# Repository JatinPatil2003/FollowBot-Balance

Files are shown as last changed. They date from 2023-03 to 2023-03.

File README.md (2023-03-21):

# FollowBot-Balance
It is a Self balancing robot whhich has a feature of following human. It uses a control system to balance the bot and opencv and media pipe to detect human, it takes video stream from esp32cam and process that video and revert back coordinates of human to the server's ip address.

This Self balancing bot can balance at a point, can be contolled over remote and can hollow human

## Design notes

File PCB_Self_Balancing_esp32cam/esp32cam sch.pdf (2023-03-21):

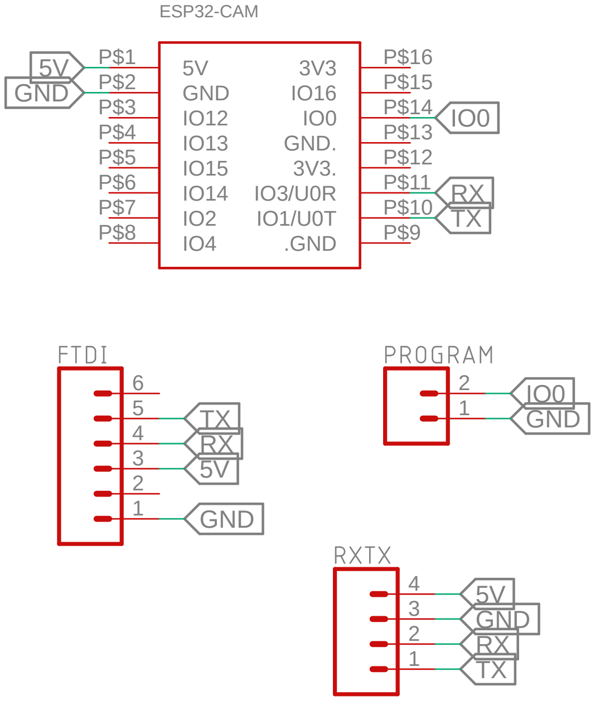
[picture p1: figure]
5V P$1 GND P$2 IO12 P$3 IO13 P$4 IO15 P$5 IO14 P$6 IO2 P$7; .GND; P$12 GND.; ESP32-CAM; GND

22-03-2023 03:23 AM f=2.50 C:\Users\jatin\OneDrive\Documents\EAGLE\projects\PCB_Self_Balancing_esp32cam\Self_Balancing esp32cam.sch (Sheet: 1/1)

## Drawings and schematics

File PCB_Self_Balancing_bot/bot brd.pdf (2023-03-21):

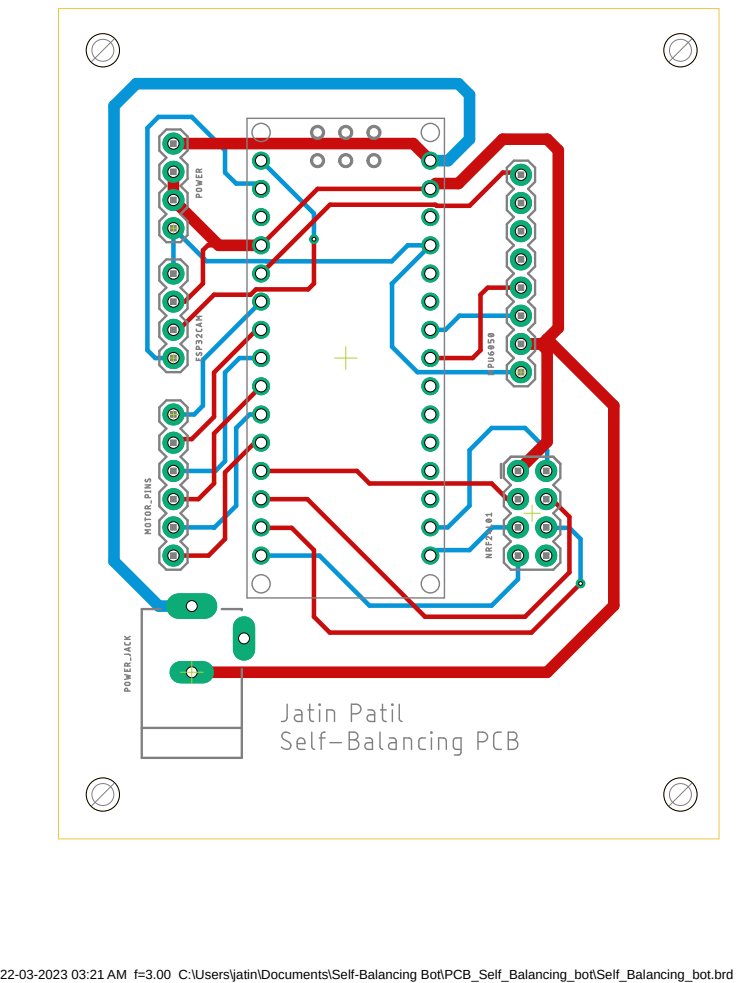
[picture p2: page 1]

22-03-2023 03:21 AM f=3.00 C:\Users\jatin\Documents\Self-Balancing Bot\PCB_Self_Balancing_bot\Self_Balancing_bot.brd

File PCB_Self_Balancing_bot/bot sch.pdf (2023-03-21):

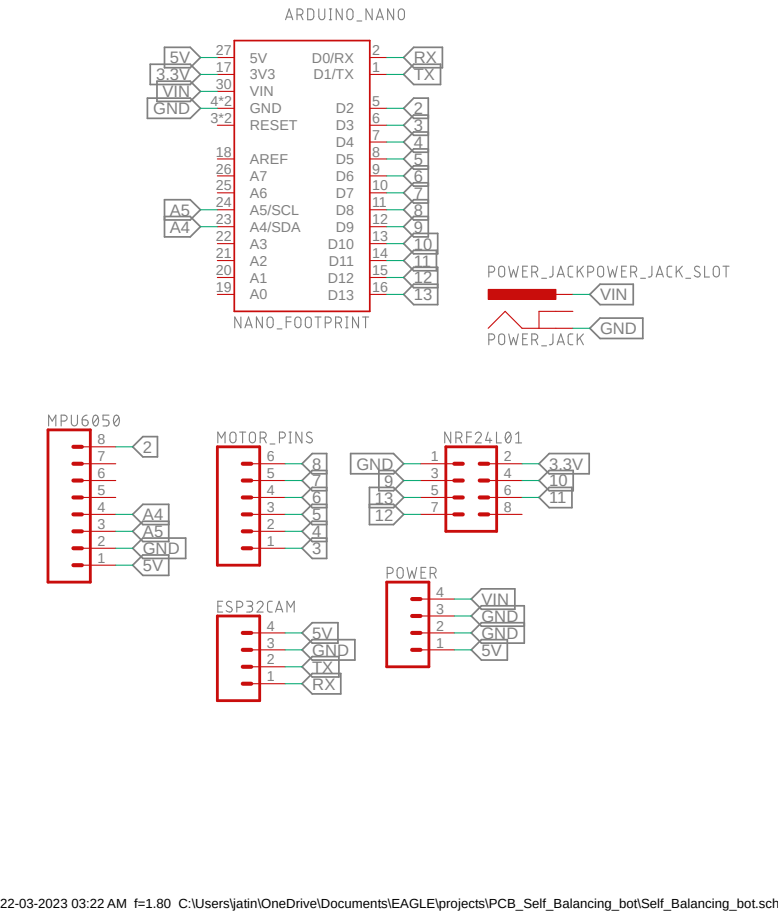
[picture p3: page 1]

22-03-2023 03:22 AM f=1.80 C:\Users\jatin\OneDrive\Documents\EAGLE\projects\PCB_Self_Balancing_bot\Self_Balancing_bot.sch (Sheet: 1/1)

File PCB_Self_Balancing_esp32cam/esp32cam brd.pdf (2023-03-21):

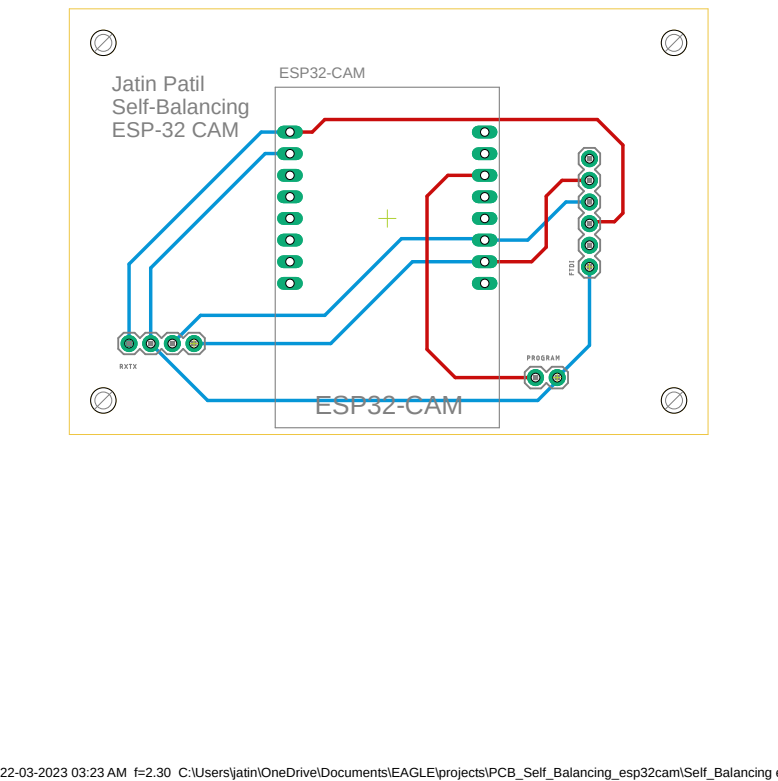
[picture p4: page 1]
ESP32-CAM; Jatin Patil Self-Balancing ESP-32 CAM

22-03-2023 03:23 AM f=2.30 C:\Users\jatin\OneDrive\Documents\EAGLE\projects\PCB_Self_Balancing_esp32cam\Self_Balancing esp32cam.brd

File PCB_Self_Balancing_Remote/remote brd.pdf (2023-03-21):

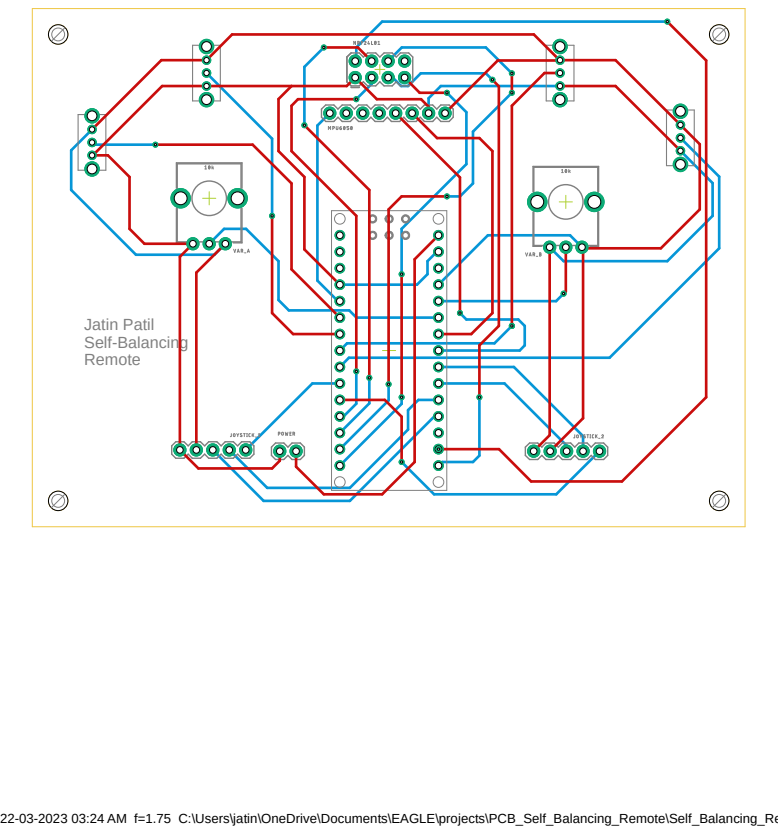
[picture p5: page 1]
Jatin Patil Self-Balancing Remote

22-03-2023 03:24 AM f=1.75 C:\Users\jatin\OneDrive\Documents\EAGLE\projects\PCB_Self_Balancing_Remote\Self_Balancing_Remote.brd

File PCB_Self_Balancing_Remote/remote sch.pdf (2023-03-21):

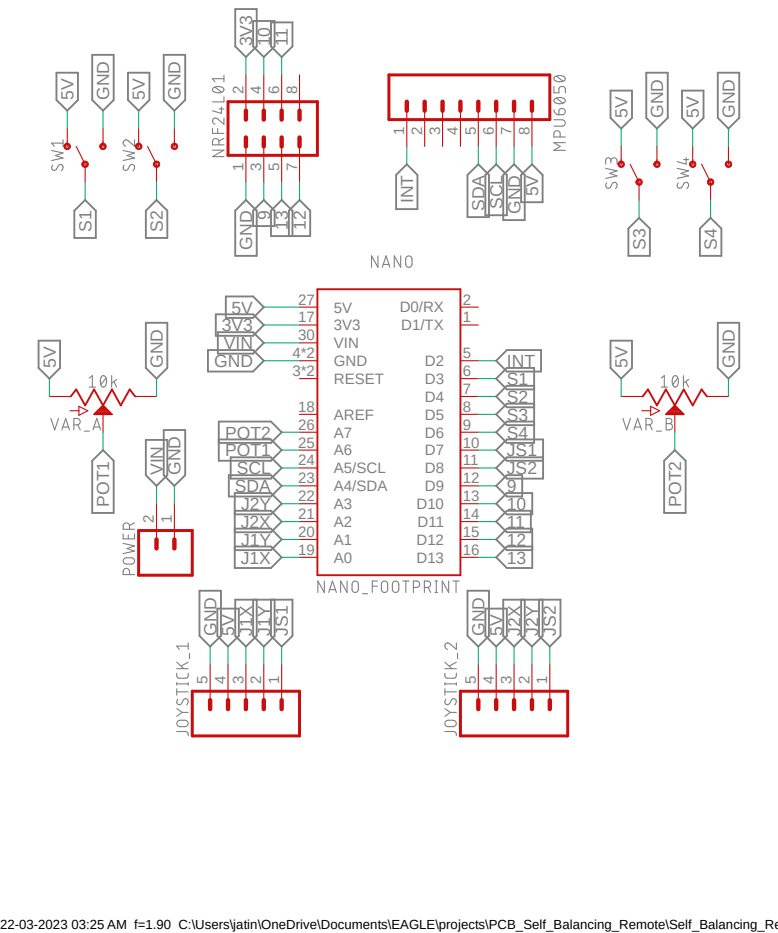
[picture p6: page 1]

22-03-2023 03:25 AM f=1.90 C:\Users\jatin\OneDrive\Documents\EAGLE\projects\PCB_Self_Balancing_Remote\Self_Balancing_Remote.sch (Sheet: 1/1)

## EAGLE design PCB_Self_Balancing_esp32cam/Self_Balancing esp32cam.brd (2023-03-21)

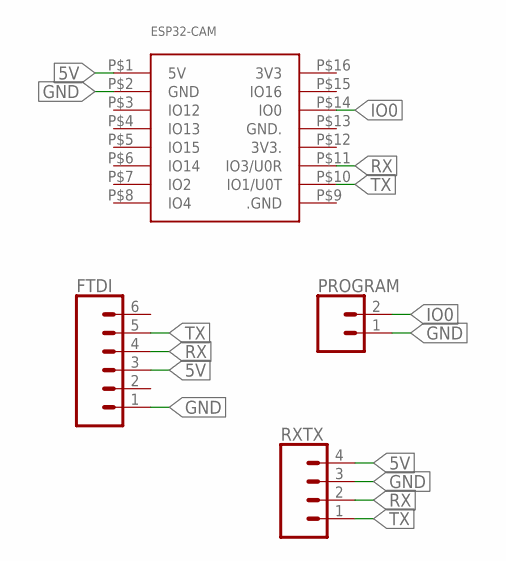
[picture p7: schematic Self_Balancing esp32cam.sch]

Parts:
ESP32-CAM: ESP32-CAM
FTDI: CONN_06SILK_FEMALE_PTH; 1X06
PROGRAM: CONN_02; 1X02
RXTX: CONN_04PTH; 1X04

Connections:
5V: ESP32-CAM.P$1 (5V), FTDI.3, RXTX.4
GND: ESP32-CAM.P$2 (GND), FTDI.1, PROGRAM.1, RXTX.3
IO0: ESP32-CAM.P$14 (IO0), PROGRAM.2
RX: ESP32-CAM.P$11 (IO3/U0R), FTDI.4, RXTX.2
TX: ESP32-CAM.P$10 (IO1/U0T), FTDI.5, RXTX.1

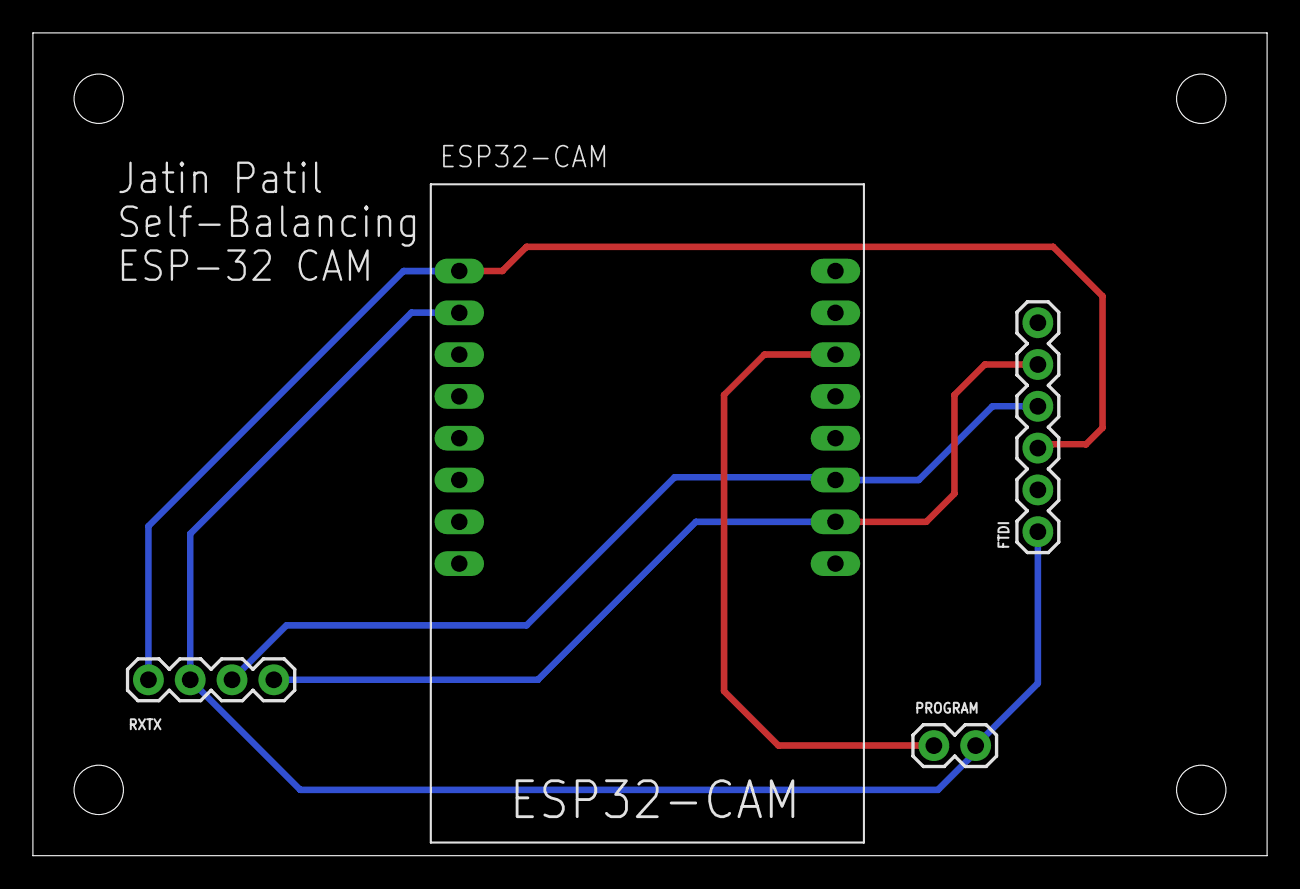
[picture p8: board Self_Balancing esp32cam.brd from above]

Board: 2 copper layers, 75.0 x 50.0 mm, 4 parts (0 on the bottom side), 5 nets.

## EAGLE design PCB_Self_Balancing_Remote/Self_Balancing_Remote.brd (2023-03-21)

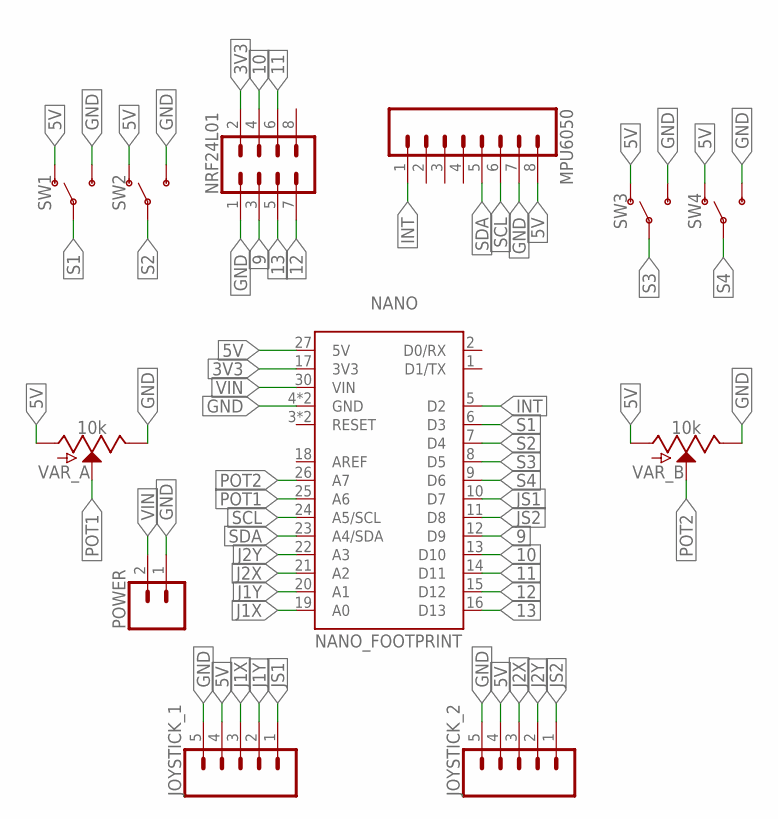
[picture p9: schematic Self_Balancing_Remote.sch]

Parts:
JOYSTICK_1, JOYSTICK_2: CONN_05; 1X05
MPU6050: CONN_08"; 1X08
NANO: NANO_FOOTPRINT; NANO
NRF24L01: CONN_04X2; 2X4
POWER: CONN_02; 1X02
SW1, SW2, SW3, SW4: SWITCH-SPDT-PTH-8.6X4.3MM; SWITCH_SPDT_8.6X4.3MM
VAR_A: 10k; POT-PTH-ALPS-KIT
VAR_B: 10k; POT-PTH-ALPS-KIT

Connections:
3V3: NANO.17 (3V3), NRF24L01.2
5V: JOYSTICK_1.4, JOYSTICK_2.4, MPU6050.8, NANO.27 (5V), SW1.1 (O), SW2.1 (O), SW3.1 (O), SW4.1 (O), VAR_A.P$3 (A), VAR_B.P$3 (A)
9: NANO.12 (D9), NRF24L01.3
10: NANO.13 (D10), NRF24L01.4
11: NANO.14 (D11), NRF24L01.6
12: NANO.15 (D12), NRF24L01.7
13: NANO.16 (D13), NRF24L01.5
GND: JOYSTICK_1.5, JOYSTICK_2.5, MPU6050.7, NANO.4 (GND), NANO.29 (GND), NRF24L01.1, POWER.1, SW1.3 (S), SW2.3 (S), SW3.3 (S), SW4.3 (S), VAR_A.P$1 (E), VAR_B.P$1 (E)
INT: MPU6050.1, NANO.5 (D2)
J1X: JOYSTICK_1.3, NANO.19 (A0)
J1Y: JOYSTICK_1.2, NANO.20 (A1)
J2X: JOYSTICK_2.3, NANO.21 (A2)
J2Y: JOYSTICK_2.2, NANO.22 (A3)
JS1: JOYSTICK_1.1, NANO.10 (D7)
JS2: JOYSTICK_2.1, NANO.11 (D8)
POT1: NANO.25 (A6), VAR_A.P$2 (S)
POT2: NANO.26 (A7), VAR_B.P$2 (S)
S1: NANO.6 (D3), SW1.2
S2: NANO.7 (D4), SW2.2
S3: NANO.8 (D5), SW3.2
S4: NANO.9 (D6), SW4.2
SCL: MPU6050.6, NANO.24 (A5/SCL)
SDA: MPU6050.5, NANO.23 (A4/SDA)
VIN: NANO.30 (VIN), POWER.2

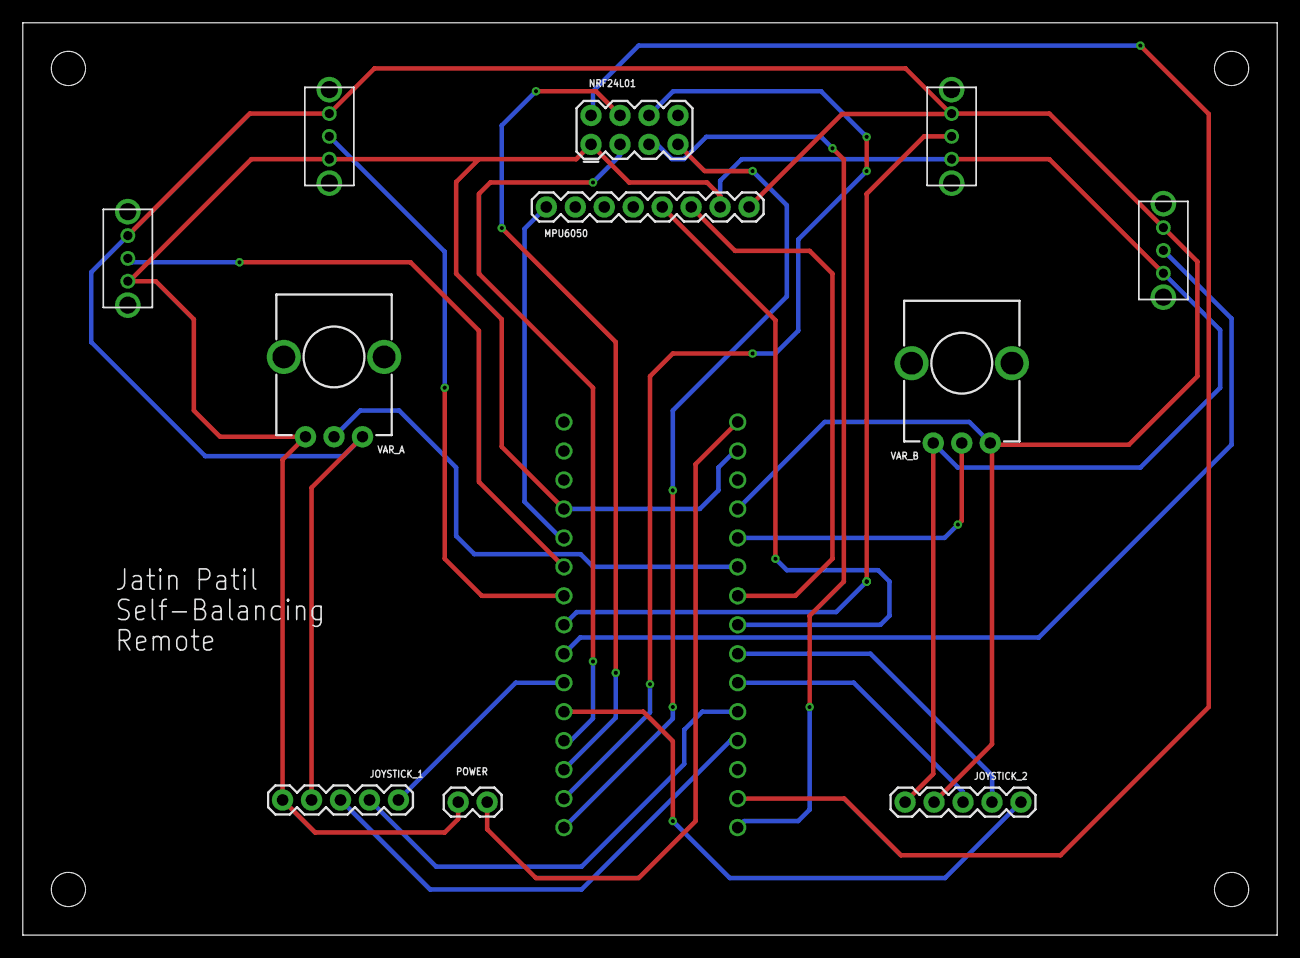
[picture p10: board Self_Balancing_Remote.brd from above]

Board: 2 copper layers, 110.0 x 80.0 mm, 12 parts (0 on the bottom side), 24 nets.

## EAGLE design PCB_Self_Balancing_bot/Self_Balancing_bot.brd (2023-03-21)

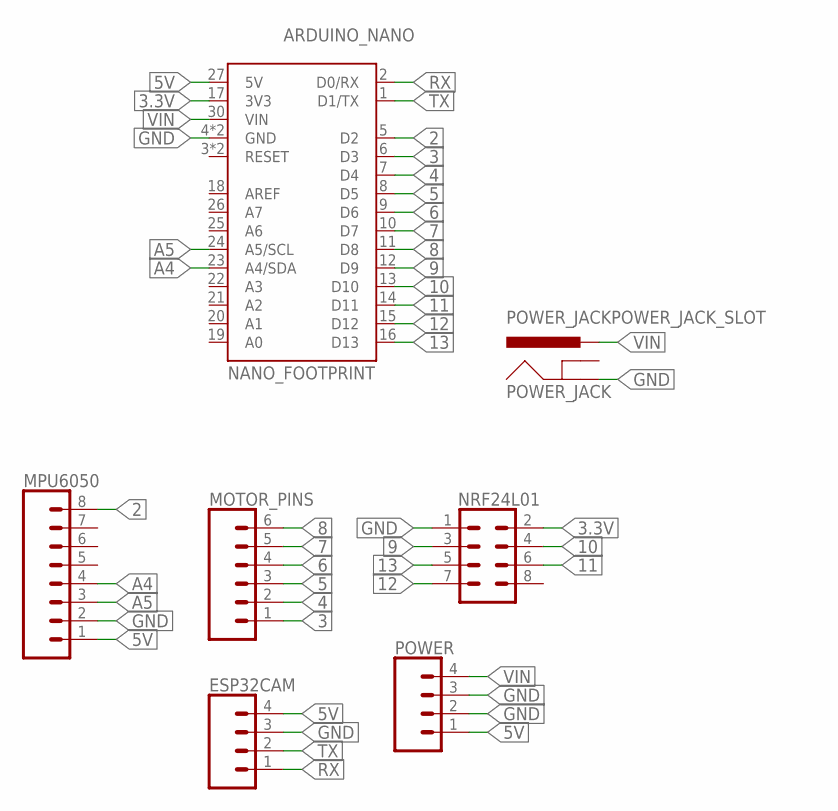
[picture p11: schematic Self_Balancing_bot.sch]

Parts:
ARDUINO_NANO: NANO_FOOTPRINT; NANO
ESP32CAM: CONN_04PTH; 1X04
MOTOR_PINS: CONN_06SILK_FEMALE_PTH; 1X06
MPU6050: CONN_08"; 1X08
NRF24L01: CONN_04X2; 2X4
POWER: CONN_04PTH; 1X04
POWER_JACK: POWER_JACKPOWER_JACK_SLOT; POWER_JACK_PTH_SLOT

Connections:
2: ARDUINO_NANO.5 (D2), MPU6050.8
3: ARDUINO_NANO.6 (D3), MOTOR_PINS.1
3.3V: ARDUINO_NANO.17 (3V3), NRF24L01.2
4: ARDUINO_NANO.7 (D4), MOTOR_PINS.2
5: ARDUINO_NANO.8 (D5), MOTOR_PINS.3
5V: ARDUINO_NANO.27 (5V), ESP32CAM.4, MPU6050.1, POWER.1
6: ARDUINO_NANO.9 (D6), MOTOR_PINS.4
7: ARDUINO_NANO.10 (D7), MOTOR_PINS.5
8: ARDUINO_NANO.11 (D8), MOTOR_PINS.6
9: ARDUINO_NANO.12 (D9), NRF24L01.3
10: ARDUINO_NANO.13 (D10), NRF24L01.4
11: ARDUINO_NANO.14 (D11), NRF24L01.6
12: ARDUINO_NANO.15 (D12), NRF24L01.7
13: ARDUINO_NANO.16 (D13), NRF24L01.5
A4: ARDUINO_NANO.23 (A4/SDA), MPU6050.4
A5: ARDUINO_NANO.24 (A5/SCL), MPU6050.3
GND: ARDUINO_NANO.4 (GND), ARDUINO_NANO.29 (GND), ESP32CAM.3, MPU6050.2, NRF24L01.1, POWER.2, POWER.3, POWER_JACK.GND
RX: ARDUINO_NANO.2 (D0/RX), ESP32CAM.1
TX: ARDUINO_NANO.1 (D1/TX), ESP32CAM.2
VIN: ARDUINO_NANO.30 (VIN), POWER.4, POWER_JACK.PWR

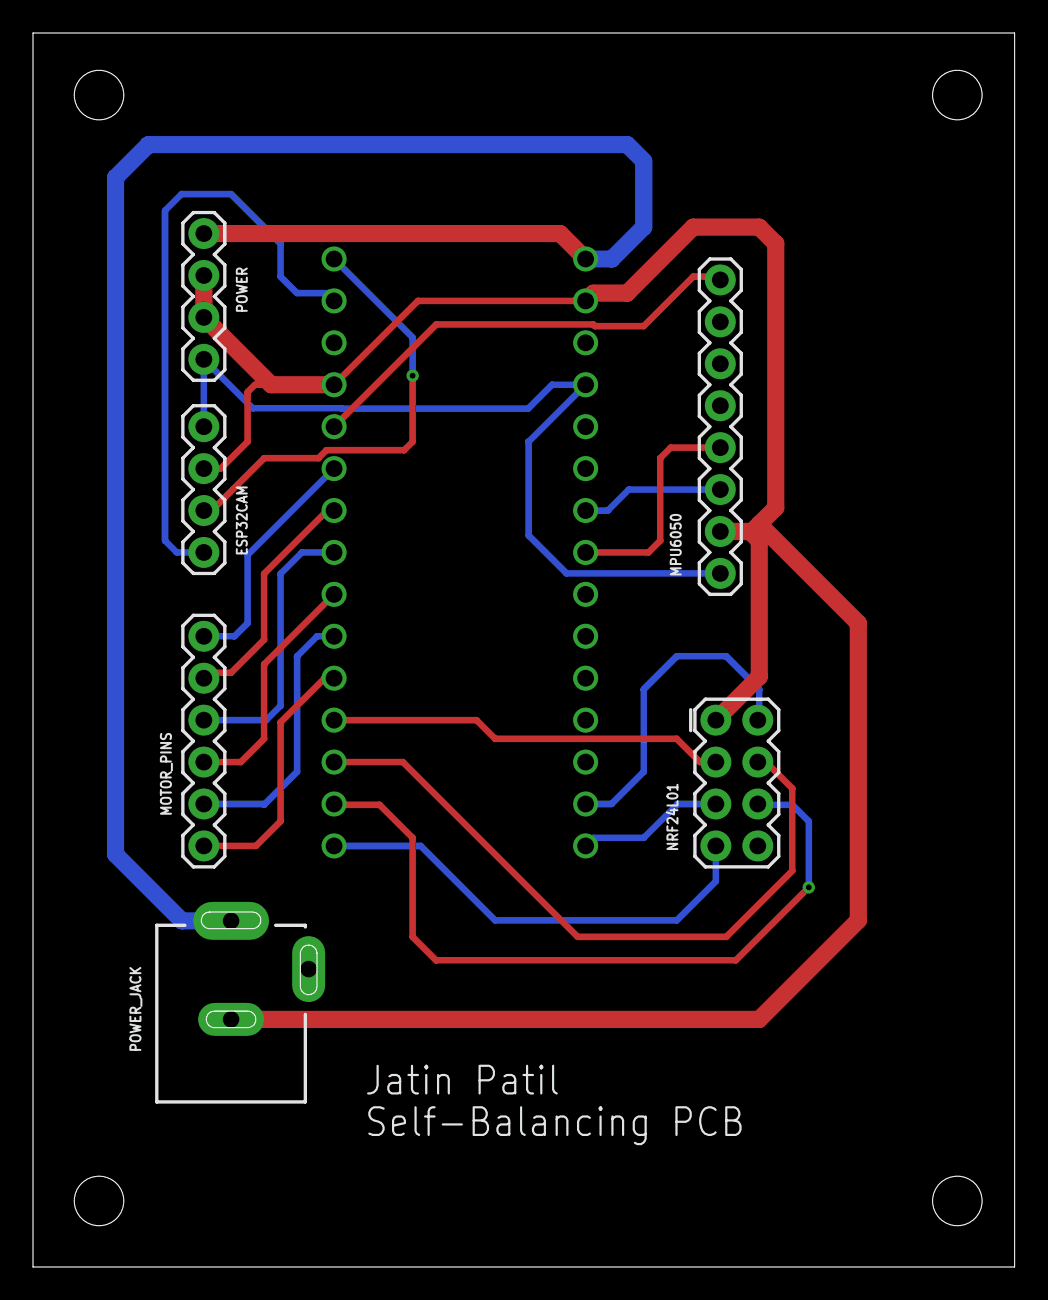
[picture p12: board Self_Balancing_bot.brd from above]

Board: 2 copper layers, 59.5 x 74.8 mm, 7 parts (0 on the bottom side), 20 nets.

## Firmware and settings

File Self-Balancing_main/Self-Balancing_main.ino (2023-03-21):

#include "I2Cdev.h"
#include <PID_v1.h>
#include "MPU6050_6Axis_MotionApps20.h"
#include <SPI.h>
#include <nRF24L01.h>
#include <RF24.h>
#define minspeed 75

struct nrfdata{
  byte J1X,J2Y;
}data;
RF24 radio(9, 10);
const byte address[6] = "00001";

MPU6050 mpu;

// MPU control/status variables
bool dmpReady = false;  // set true if DMP init was successful
uint8_t mpuIntStatus;   // holds actual interrupt status byte from MPU
uint8_t devStatus;      // return status after each device operation (0 = success, !0 = error)
uint16_t packetSize;    // expected DMP packet size (default is 42 bytes)
uint16_t fifoCount;     // count of all bytes currently in FIFO
uint8_t fifoBuffer[64]; // FIFO storage buffer

// orientation/motion variables
Quaternion q;           // [w, x, y, z]         quaternion container
VectorFloat gravity;    // [x, y, z]            gravity vector
float ypr[3];           // [yaw, pitch, roll]   yaw/pitch/roll container and gravity vector


//............set following 4 values for your robot....
double setpoint = 184.2;
double Kp = 10.5; //Set this first
double Kd = 0.3937; //Set this secound
double Ki = 70; //Finally set this
//..............................................

double input, output;
PID pid(&input, &output, &setpoint, Kp, Ki, Kd, DIRECT);



volatile bool mpuInterrupt = false;     // indicates whether MPU interrupt pin has gone high
void dmpDataReady()
{
  mpuInterrupt = true;
}

void setup() {
  Serial.begin(115200);
  Wire.begin();
  Wire.setClock(400000);
  Serial.println(F("Initializing I2C devices..."));
  mpu.initialize();
  pinMode(2, INPUT);

  // verify connection
  Serial.println(F("Testing device connections..."));
  Serial.println(mpu.testConnection() ? F("MPU6050 connection successful") : F("MPU6050 connection failed"));

  // load and configure the DMP
  devStatus = mpu.dmpInitialize();


  // supply your own gyro offsets here, scaled for min sensitivity
//  Your offsets  -1966 -1101 1139  690 -20 -19
//
//  Data is prited as: acelX acelY aclZ giro iroY giroZ

  mpu.setXGyroOffset(690);
  mpu.setYGyroOffset(-20);
  mpu.setZGyroOffset(-19);
  mpu.setZAccelOffset(1139);

  // make sure it worked (returns 0 if so)
  if (devStatus == 0)
  {
    // turn on the DMP, now that it's ready
    Serial.println(F("Enabling DMP..."));
    mpu.setDMPEnabled(true);

    // enable Arduino interrupt detection
    Serial.println(F("Enabling interrupt detection (Arduino external interrupt 0)..."));
    attachInterrupt(digitalPinToInterrupt(2), dmpDataReady, RISING);
    mpuIntStatus = mpu.getIntStatus();

    // set our DMP Ready flag so the main loop() function knows it's okay to use it
    Serial.println(F("DMP ready! Waiting for first interrupt..."));
    dmpReady = true;

    // get expected DMP packet size for later comparison
    packetSize = mpu.dmpGetFIFOPacketSize();

    //setup PID
    pid.SetMode(AUTOMATIC);
    pid.SetSampleTime(10);
    pid.SetOutputLimits(-180, 180);
  }
  else
  {
    // ERROR!
    // 1 = initial memory load failed
    // 2 = DMP configuration updates failed
    // (if it's going to break, usually the code will be 1)
    Serial.print(F("DMP Initialization failed (code "));
    Serial.print(devStatus);
    Serial.println(F(")"));
  }

  //Initialise the Motor output pins
  pinMode (3, OUTPUT);
  pinMode (4, OUTPUT);
  pinMode (5, OUTPUT);
  pinMode (6, OUTPUT);
  pinMode (7, OUTPUT);
  pinMode (8, OUTPUT);

  //By default turn off both the motors
  digitalWrite(3, LOW);
  digitalWrite(4, LOW);
  digitalWrite(7, LOW);
  digitalWrite(8, LOW);
  analogWrite(5,0);
  analogWrite(6,0);
  radio.begin();
  radio.openReadingPipe(0, address);
  radio.setPALevel(RF24_PA_MIN);
  radio.startListening();
}



void loop() {

  // if programming failed, don't try to do anything
  if (!dmpReady) return;

  // wait for MPU interrupt or extra packet(s) available
  while (!mpuInterrupt && fifoCount < packetSize)
  {
    //no mpu data - performing PID calculations and output to motors
    data.J1X = 128;
    data.J2Y = 128;
    
    radio.read(&data,sizeof(struct nrfdata));
    int mov = 0;
    if(data.J1X > 150){
      mov = map(data.J1X,150,255,0,3);
    }
    else if(data.J1X < 100){
      mov = map(data.J1X,0,100,-3,0);
    }
    else{
      mov = 0;
    }
    setpoint += mov;
//    Serial.print(mov);Serial.print(" || ");
    pid.Compute();

    //Print the value of Input and Output on serial monitor to check how it is working.
    Serial.print(input); Serial.print(" =>"); Serial.println(output);
    
    int rot = 0;
    if(data.J2Y > 150){
      rot = map(data.J2Y,150,255,0,50);
    }
    else if(data.J2Y < 100){
      rot = map(data.J2Y,0,100,-50,0);
    }
    else{
      rot = 0;
    }
//    Serial.print(" || ");Serial.println(rot);
    if (input > 150 && input < 200) { //If the Bot is falling

      if (output > 0) //Falling towards front
        Forward(rot); //Rotate the wheels forward
      else if (output < 0) //Falling towards back
        Backward(rot); //Rotate the wheels backward
    }
    else //If Bot not falling
      Stop(); //Hold the wheels still

    setpoint -= mov;

  }

  // reset interrupt flag and get INT_STATUS byte
  mpuInterrupt = false;
  mpuIntStatus = mpu.getIntStatus();

  // get current FIFO count
  fifoCount = mpu.getFIFOCount();

  // check for overflow (this should never happen unless our code is too inefficient)
  if ((mpuIntStatus & 0x10) || fifoCount == 1024)
  {
    // reset so we can continue cleanly
    mpu.resetFIFO();
    Serial.println(F("FIFO overflow!"));

    // otherwise, check for DMP data ready interrupt (this should happen frequently)
  }
  else if (mpuIntStatus & 0x02)
  {
    // wait for correct available data length, should be a VERY short wait
    while (fifoCount < packetSize) fifoCount = mpu.getFIFOCount();

    // read a packet from FIFO
    mpu.getFIFOBytes(fifoBuffer, packetSize);
    fifoCount -= packetSize;

    mpu.dmpGetQuaternion(&q, fifoBuffer); 
    mpu.dmpGetGravity(&gravity, &q);
    mpu.dmpGetYawPitchRoll(ypr, &q, &gravity); 

    input = ypr[1] * 180 / M_PI + 180;
    //        Serial.println("ypr[1]=");
    //Serial.println(ypr[1]);
  }
}

void Forward(int con) //Rotate the wheel forward
{
  digitalWrite(3, HIGH);
  digitalWrite(4, LOW);
  digitalWrite(7, HIGH);
  digitalWrite(8, LOW);
  analogWrite(5,constrain(output+con+minspeed,minspeed,255));
  analogWrite(6,constrain(output-con+minspeed,minspeed,255));
}

void Backward(int con) //Rotate the wheel Backward
{
  digitalWrite(4, HIGH);
  digitalWrite(3, LOW);
  digitalWrite(8, HIGH);
  digitalWrite(7, LOW);
  analogWrite(5,constrain((output*-1)-con+minspeed,minspeed,255));
  analogWrite(6,constrain((output*-1)+con+minspeed,minspeed,255));
}

void Stop() //Stop both the wheels
{
  digitalWrite(3, LOW);
  digitalWrite(4, LOW);
  digitalWrite(7, LOW);
  digitalWrite(8, LOW);
  analogWrite(5,0);
  analogWrite(6,0);
}

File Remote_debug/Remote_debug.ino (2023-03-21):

#define switchPin1 3
#define switchPin2 4
#define switchPin3 5
#define switchPin4 6
#define potPin1 A7
#define potPin2 A6
#define joyPin1_1 A2
#define joyPin1_2 A3
#define joyPin2_1 A0
#define joyPin2_2 A1
struct nrfdata{
  int S1,S2,S3,S4;
  int Pot1,Pot2;
  int J1X,J1Y,J2X,J2Y;
}data;


void setup() {
  // put your setup code here, to run once:
  pinMode(switchPin1,INPUT);
  pinMode(switchPin2,INPUT);
  pinMode(switchPin3,INPUT);
  pinMode(switchPin4,INPUT);
  Serial.begin(9600);
}

void loop() {
  // put your main code here, to run repeatedly:
  data.S1 = digitalRead(switchPin1);
  data.S2 = digitalRead(switchPin2);
  data.S3 = digitalRead(switchPin3);
  data.S4 = digitalRead(switchPin4);
  data.Pot1 = analogRead(potPin1);
  data.Pot2 = analogRead(potPin2);
  data.J1X = analogRead(joyPin1_1);
  data.J1Y = analogRead(joyPin1_2);
  data.J2X = analogRead(joyPin2_1);
  data.J2Y = analogRead(joyPin2_2);
  delay(100);
  Serial.print("----------------------------------------\n");
  Serial.print(" | ");
  Serial.print(data.J1X);
  Serial.print(" | ");
  Serial.print(data.J1Y);
  Serial.print(" | ");
  Serial.print(data.J2X);
  Serial.print(" | ");
  Serial.print(data.J2Y);
  Serial.print(" | ");
  Serial.print(data.Pot1);
  Serial.print(" | ");
  Serial.print(data.Pot2);
  Serial.print(" | ");
  Serial.print(data.S1);
  Serial.print(" | ");
  Serial.print(data.S2);
  Serial.print(" | ");
  Serial.print(data.S3);
  Serial.print(" | ");
  Serial.print(data.S4);
  Serial.print("\n");
}

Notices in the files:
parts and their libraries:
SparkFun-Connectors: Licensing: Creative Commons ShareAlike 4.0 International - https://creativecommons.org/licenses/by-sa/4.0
